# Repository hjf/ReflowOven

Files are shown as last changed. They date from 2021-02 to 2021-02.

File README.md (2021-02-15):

# ESP8266 Reflow Oven Controller
*Instrucciones en español mas abajo*
## Introduction

This is a simple PID controller with a web interface for a reflow oven. It requires a MAX31856, a K-type thermocouple, a MOC3041 optotriac, a suitable triac for your mains voltage, and a ESP-12E module. 

### Software

The Arduino-based firmware is included. It requres tzapu's [WiFiManager](https://github.com/tzapu/WiFiManager) to set up. It also includes ArduinoOTA for remote firmware upgrades.

### Hardware

The KiCAD files are available too, but this is a simple circuit that can, obviously, be built out of standard arduino modules. Instead of the triac and optotriac, a SSR (Solid State Relay) can be used. A mechanical relay cannot be used as this circuit switches the load several times per second for accurate temperature control.

---

## Introducción

Este es un controlador PID muy simple, con una interfaz web, para controlar un horno de soldadura por refusion. Necesita un MAX31856, una termocupla tipo K, un optotriac MOC3041, un triac adecuado para tu voltaje de linea, y un modulo ESP-12E

### Software

Se incluye el firmware basado en Arduino. Necesita la libreria [WiFiManager](https://github.com/tzapu/WiFiManager) de tzapu para la configuracion. Tambien incluye ArduinoOTA para actualizaciones remotas.

### Hardware

También se incluyen los archivos de KiCAD, pero este es un circuito tan simple que obviamente se puede armar con modulos Arduino comunes. En lugar del triac y optotriac, se puede usar un modulo SSR. No es posible usar un relay mecánico ya que el circuito conmuta la salida varias veces por segundo para un control preciso de la temperatura.

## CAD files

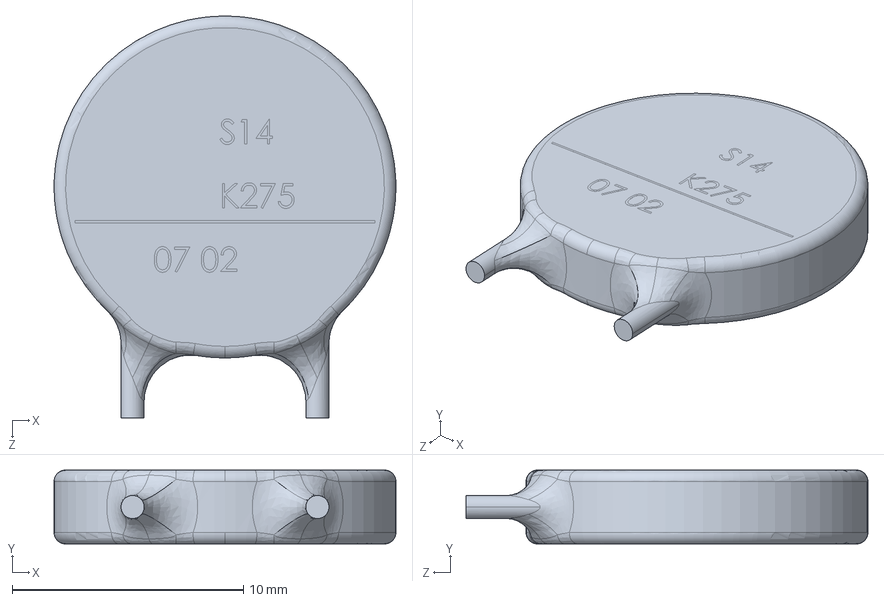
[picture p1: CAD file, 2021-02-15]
KiCAD files/Varistor.STEP
14.8 x 3.20 x 17.4 mm

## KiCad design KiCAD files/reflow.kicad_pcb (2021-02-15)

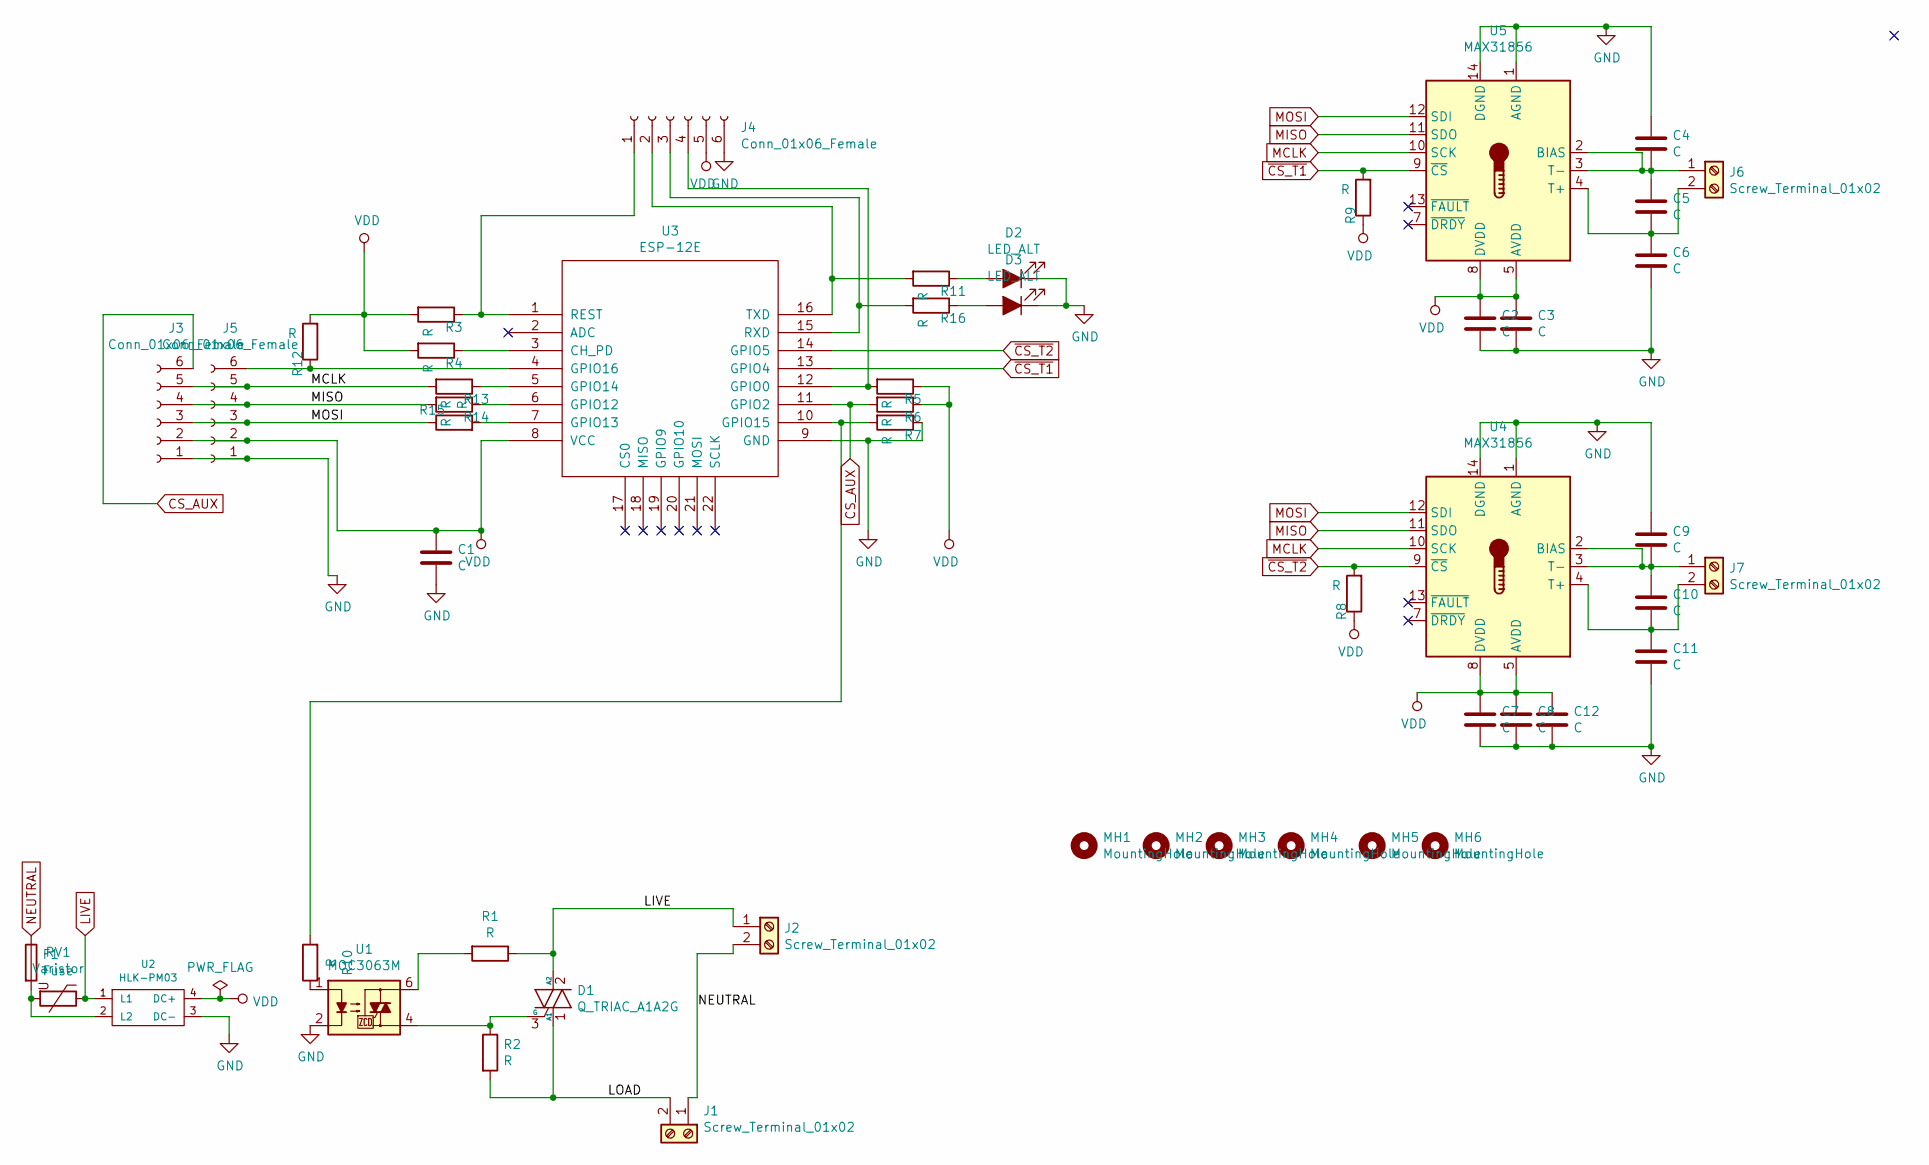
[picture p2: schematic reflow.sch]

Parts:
C1: C; CP_Tantalum_Case-C_EIA-6032-28_Hand
C2, C3, C4, C5, C6, C7, C8, C9, C10, C11, C12: C; R_0805
D1: Q_TRIAC_A1A2G; to220_std_14cw
D2, D3: LED_ALT; LED_0805_HandSoldering
F1: Fuse; FC-211
J1, J2, J6, J7: Screw_Terminal_01x02; mkds_1,5-2
J3, J4, J5: Conn_01x06_Female; Pin_Header_Straight_1x06_Pitch2.54mm
MH1, MH2, MH3, MH4, MH5, MH6: MountingHole; MountingHole_3.2mm_M3
R1, R2: R; R_Axial_DIN0207_L6.3mm_D2.5mm_P10.16mm_Horizontal
R3, R4, R5, R6, R7, R8, R9, R10, R11, R12, R13, R14, R15, R16: R; R_0805
RV1: Varistor; RV_Disc_D12_W3.9_P7.5
U1: MOC3063M; DIP-6_W7.62mm
U2: HLK-PM03
U3: ESP-12E; ESP-12E_SMD
U4, U5: MAX31856; TSSOP-14_4.4x5mm_Pitch0.65mm

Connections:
/LOAD: D1.1 (A1), J1.2, R2.2
CS_AUX: J3.6, R6.2, U3.11 (GPIO2)
GND: C1.2, C2.2, C3.2, C4.1, C6.2, C7.2, C8.2, C9.1, C11.2, C12.2, D2.1 (K), D3.1 (K), J3.1, J4.6, J5.1, R7.1, U1.2, U2.3 (DC-), U3.9 (GND), U4.1 (AGND), U4.14 (DGND), U5.1 (AGND), U5.14 (DGND)
LIVE: D1.2 (A2), J2.1, R1.1, RV1.1, U2.1 (L1)
MCLK: J3.5, J5.5, R13.2, U4.10 (SCK), U5.10 (SCK)
MISO: J3.4, J5.4, R14.2, U4.11 (SDO), U5.11 (SDO)
MOSI: J3.3, J5.3, R15.1, U4.12 (SDI), U5.12 (SDI)
NEUTRAL: F1.1, J1.1, J2.2
unnamed: C4.2, C5.1, J6.1, U5.2 (BIAS), U5.3 (T-)
unnamed: C5.2, C6.1, J6.2, U5.4 (T+)
unnamed: C9.2, C10.1, J7.1, U4.2 (BIAS), U4.3 (T-)
unnamed: C10.2, C11.1, J7.2, U4.4 (T+)
unnamed: D1.3 (G), R2.1, U1.4
unnamed: D2.2 (A), R11.1
unnamed: D3.2 (A), R16.1
unnamed: F1.2, RV1.2, U2.2 (L2)
unnamed: J4.1, R3.1, U3.1 (REST)
unnamed: J4.2, R11.2, U3.16 (TXD)
unnamed: J4.3, R16.2, U3.15 (RXD)
unnamed: J4.4, R5.2, U3.12 (GPIO0)
unnamed: J5.6, R12.1, U3.4 (GPIO16)
unnamed: R1.2, U1.6
unnamed: R4.1, U3.3 (CH_PD)
unnamed: R10.1, U1.1
unnamed: R7.2, R10.2, U3.10 (GPIO15)
unnamed: R13.1, U3.5 (GPIO14)
unnamed: R14.1, U3.6 (GPIO12)
unnamed: R15.2, U3.7 (GPIO13)
VDD: C1.1, C2.1, C3.1, C7.1, C8.1, C12.1, J3.2, J4.5, J5.2, R3.2, R4.2, R5.1, R6.1, R8.1, R9.1, R12.2, U2.4 (DC+), U3.8 (VCC), U4.5 (AVDD), U4.8 (DVDD), U5.5 (AVDD), U5.8 (DVDD)
~CS_T1: R9.2, U3.13 (GPIO4), U5.9 (~CS)
~CS_T2: R8.2, U3.14 (GPIO5), U4.9 (~CS)

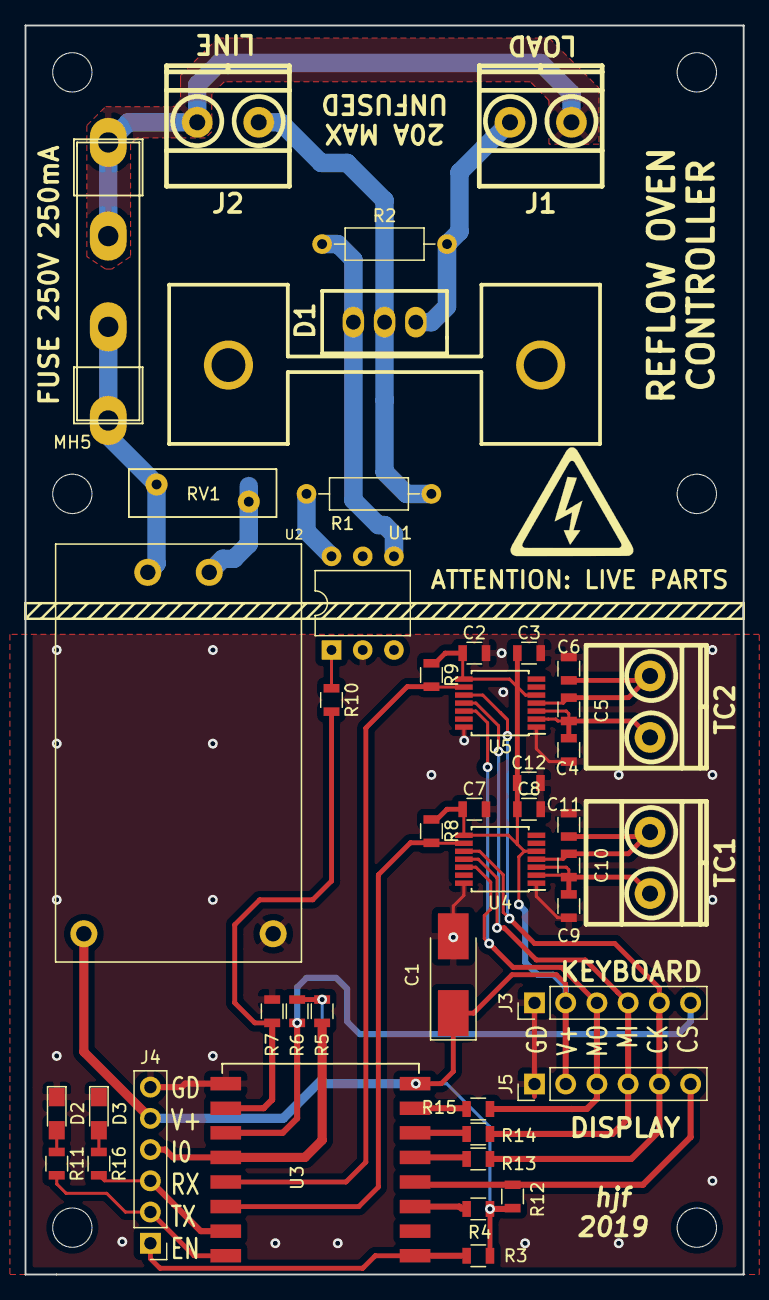
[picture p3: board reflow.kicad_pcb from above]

Board: 2 copper layers, 58.4 x 101.6 mm, 51 parts (0 on the bottom side), 31 nets.

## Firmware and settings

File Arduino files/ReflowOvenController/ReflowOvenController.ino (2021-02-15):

#include <ESP8266WiFi.h>          //ESP8266 Core WiFi Library (you most likely already have this in your sketch)
#include <DNSServer.h>            //Local DNS Server used for redirecting all requests to the configuration portal
#include <ESP8266WebServer.h>     //Local WebServer used to serve the configuration portal
#include <WiFiManager.h>
#include <Adafruit_MAX31856.h>

#include <ArduinoOTA.h>
#include "mytypes.h"
#include "WebServer.h"
#include "config.h"
#include <PID_v1.h>
double Kp = 25, Ki = 15, Kd = 8;
bool tuningsChanged = false;


#define WITH_SERIAL
#ifdef HARDWARE_SPI
Adafruit_MAX31856 tc1 = Adafruit_MAX31856(TC1_CS);
#else
Adafruit_MAX31856 tc1 = Adafruit_MAX31856(TC1_CS, MOSI, MISO, MCLK); //CS, DI, DO, CLK
#endif
thermocouple_reading_t tc_reading;
oven_status_t oven_status = BAKING;
uint32_t triac_millis = 0;
uint32_t triac_millis_setpoint = 0;
uint32_t triac_value = 100;
uint32_t pid_millis = 0;
double Setpoint, Input, Output;
float starting_temp;
oven_status_t last_oven_status;
profile_t current_profile;
uint32_t state_millis;
int32_t remaining_seconds;
bool temp_reached;

PID myPID(&Input, &Output, &Setpoint, Kp, Ki, Kd, DIRECT);

void setup() {


  WiFiManager wifiManager;
  wifiManager.autoConnect("REFLOW OVEN");
  tc1.begin();
  tc1.setThermocoupleType(MAX31856_TCTYPE_K);
  tc1.setNoiseFilter(MAX31856_NOISE_FILTER_50HZ);
  tc_reading.cold_junction_temperature = 0;
  tc_reading.thermocouple_temperature = 0;
  tc_reading.cold_junction_temperature = 0xff;
  webserver_init();

#ifdef WITH_SERIAL
  Serial.begin(115200);
#else
  pinMode(1, FUNCTION_3);  //GPIO 1 (TX) swap the pin to a GPIO.
  pinMode(3, FUNCTION_3); //GPIO 3 (RX) swap the pin to a GPIO.
#endif


  ArduinoOTA.onStart([]() {
    String type;
    if (ArduinoOTA.getCommand() == U_FLASH) {
      type = "sketch";
    } else { // U_SPIFFS
      type = "filesystem";
    }

    // NOTE: if updating SPIFFS this would be the place to unmount SPIFFS using SPIFFS.end()
    Serial.println("Start updating " + type);
  });
  ArduinoOTA.onEnd([]() {
    Serial.println("\nEnd");
  });
  ArduinoOTA.onProgress([](unsigned int progress, unsigned int total) {
    Serial.printf("Progress: %u%%\r", (progress / (total / 100)));
  });
  ArduinoOTA.onError([](ota_error_t error) {
    Serial.printf("Error[%u]: ", error);
    if (error == OTA_AUTH_ERROR) {
      Serial.println("Auth Failed");
    } else if (error == OTA_BEGIN_ERROR) {
      Serial.println("Begin Failed");
    } else if (error == OTA_CONNECT_ERROR) {
      Serial.println("Connect Failed");
    } else if (error == OTA_RECEIVE_ERROR) {
      Serial.println("Receive Failed");
    } else if (error == OTA_END_ERROR) {
      Serial.println("End Failed");
    }
  });
  ArduinoOTA.begin();
  Serial.println("Ready");
  Serial.print("IP address: ");
  Serial.println(WiFi.localIP());
  pinMode(TRIAC_ENABLE, OUTPUT);
  digitalWrite(TRIAC_ENABLE, LOW);
  tc1.oneShotTemperature(false);
  myPID.SetOutputLimits(0, TRIAC_PERIOD);
  myPID.SetMode(AUTOMATIC);

  current_profile.soak_target = 150;
  current_profile.soak_time = 90;
  current_profile.reflow_target = 230;
  current_profile.reflow_time = 35;
  current_profile.cooling_target = 60;

  oven_status = IDLE;
  tc_reading.fault = 1;
  remaining_seconds = -1;
}

void loop() {

  if (oven_status == IDLE) {
    digitalWrite(TRIAC_ENABLE, LOW);
    triac_value = 0;
    Output = 0;
  }
  //TC
  if (!tc_reading.fault) {
    if (last_oven_status != oven_status) {
      last_oven_status = oven_status;
      state_millis = millis();
      remaining_seconds = -1;
      starting_temp = tc_reading.thermocouple_temperature;
      temp_reached = false;
    }
    uint32_t state_secs = (millis() - state_millis) / 1000;


    if (oven_status == SOAK) {
      Setpoint = current_profile.soak_target;

      if (tc_reading.thermocouple_temperature  >= current_profile.soak_target)
        if (temp_reached == false) {
          temp_reached = true;
          state_millis = millis();
          state_secs = (millis() - state_millis) / 1000;
        }

      if (temp_reached)
        remaining_seconds = current_profile.soak_time - state_secs;

      if ( temp_reached && state_secs > current_profile.soak_time)
        oven_status = REFLOW;
    }

    else if (oven_status == REFLOW) {
      Setpoint = current_profile.reflow_target;
      if (tc_reading.thermocouple_temperature  >= current_profile.reflow_target)
        if (temp_reached == false) {
          temp_reached = true;
          state_millis = millis();
          state_secs = (millis() - state_millis) / 1000;
        }

      if (temp_reached)
        remaining_seconds = current_profile.reflow_time - state_secs;

      if ( temp_reached && state_secs > current_profile.reflow_time)
        oven_status = COOLING;
    }


    else if (oven_status == COOLING) {
      Setpoint = current_profile.cooling_target;
      if (tc_reading.thermocouple_temperature < current_profile.cooling_target)
        oven_status = IDLE;
    }
  }

  if (tuningsChanged) {
    myPID.SetTunings(Kp, Ki, Kd);
    tuningsChanged = false;
  }
  if (tc1.isConversionDone()) {
    tc_reading.cold_junction_temperature = tc1.readCJTemperature(false);
    tc_reading.thermocouple_temperature = tc1.readThermocoupleTemperature(false);
    tc_reading.fault = tc1.readFault();
    tc1.oneShotTemperature(false);
    if (oven_status != IDLE && millis() - pid_millis > PID_sampleTime ) {
      pid_millis = millis();
      Input = tc_reading.thermocouple_temperature;
      myPID.Compute();
      triac_value = Output;
    }
  }
  yield();
  webserver_handle();
  yield();
  ArduinoOTA.handle();
  yield();

  uint32_t ttime = millis() - triac_millis;

  if (ttime > TRIAC_PERIOD) {
    triac_millis = millis();
    if (oven_status && triac_value > 5)
      digitalWrite(TRIAC_ENABLE, HIGH);
  }
  else if (ttime > triac_value) {
    digitalWrite(TRIAC_ENABLE, LOW);
  }


#ifdef WITH_SERIAL
  //  Serial.print("CJ: ");
  //  Serial.println(tc_reading.cold_junction_temperature);
  //  Serial.print("TC: ");
  //  Serial.println(tc_reading.thermocouple_temperature);
  //  Serial.print("FAULT: ");
  //  Serial.println(tc_reading.cold_junction_temperature);
#endif
  yield();

}

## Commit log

2021-02-15 fix triac direction
    [reflow.kicad_pcb]
2021-02-15 deleted outdated gerbers
    [reflow-B.Adhes.gbr, reflow-B.CrtYd.gbr, reflow-B.Cu.gbr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]
